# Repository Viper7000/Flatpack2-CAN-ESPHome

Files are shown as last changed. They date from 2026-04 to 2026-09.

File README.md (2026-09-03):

# Flatpack2-CAN-ESPHome
Controller board for monitor and configure Eltek Flatpak2 HE PSU by CANBUS protocol using ESPhome.
Config for ESP32-Nodemcu-32 and ESP32-S3-Zero.
Included fonts and images for ESPHome.

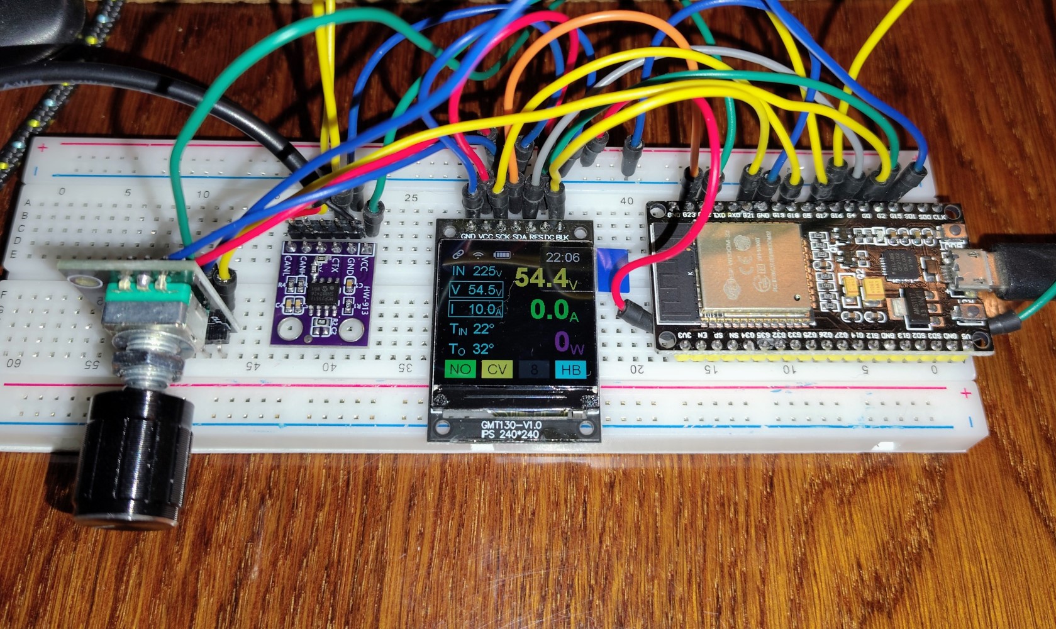
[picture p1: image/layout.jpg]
layout


## Schematics

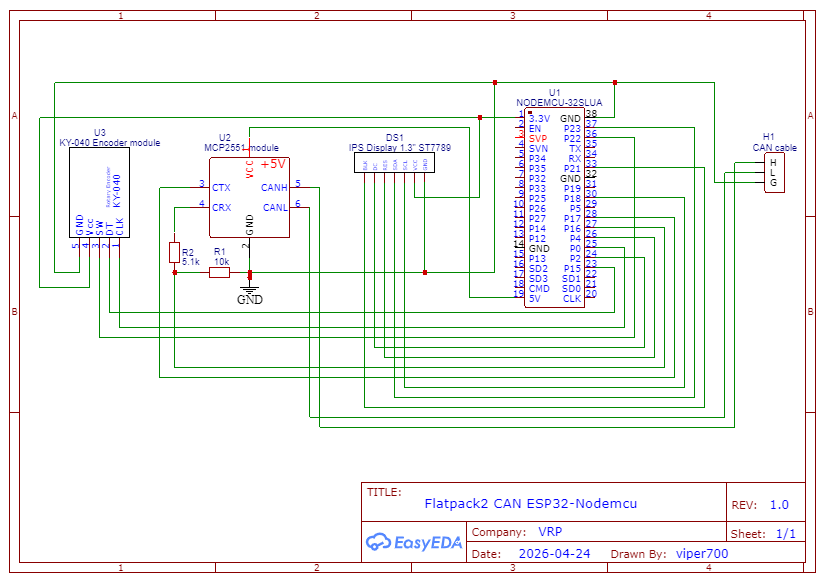
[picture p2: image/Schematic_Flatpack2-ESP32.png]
layout ESP32


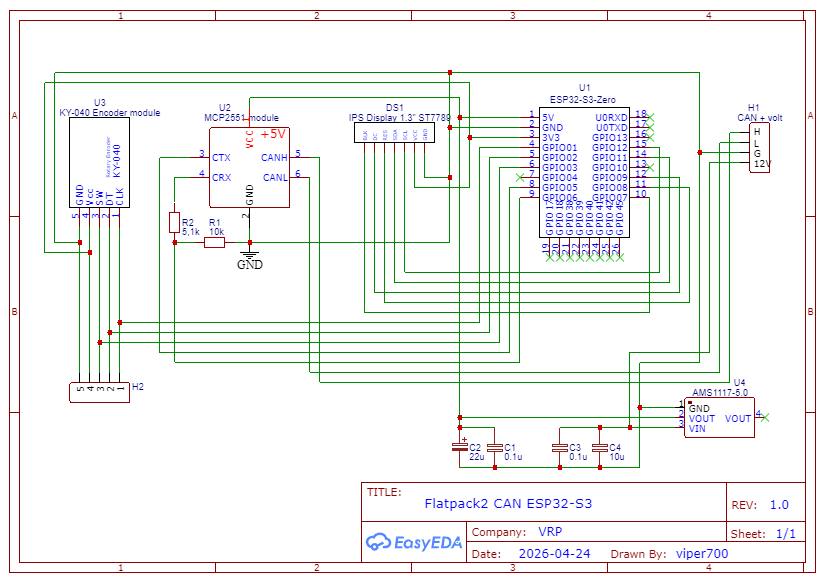
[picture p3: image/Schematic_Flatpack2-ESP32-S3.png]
layout ESP32-S3


I decided to assemble it on the ESP32-S3. I designed the board and sent the order to JLCPCB.  
Here is the [Gerber](files/Gerber_Flatpack2-ESP32-S3_PCB.zip) for ordering the PCB and the [BOM](files/BOM_Flatpack2-ESP32-S3.csv) file of components.  
I received the boards from JLCPCB for this power supply.  

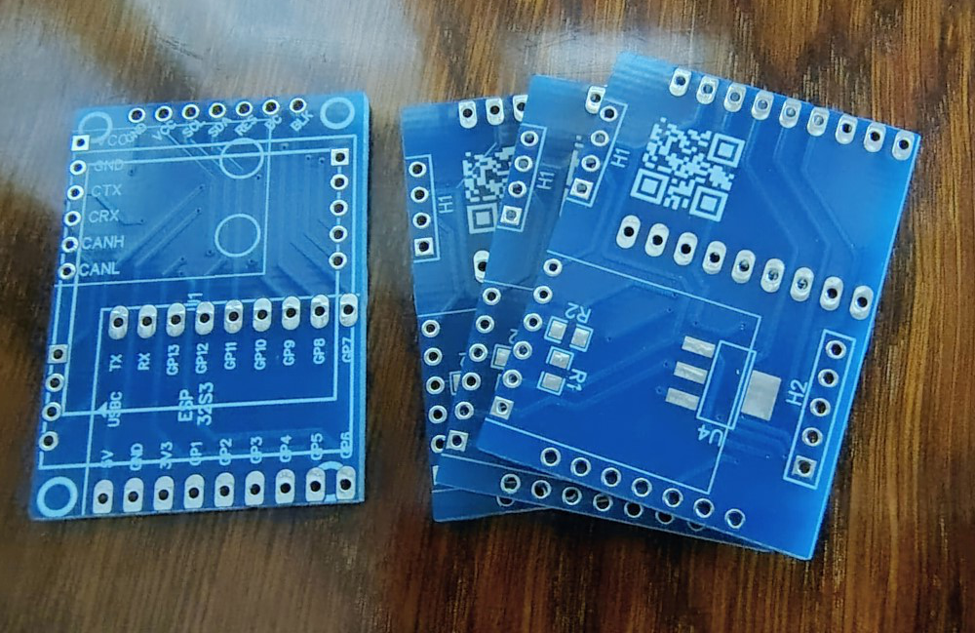
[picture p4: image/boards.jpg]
layout Boards


> :warning: This board has an error: the ASM1117-5.0 is missing a capacitor harness. This error has been fixed in the BOM and Gerber. I didn't print a new board and fixed it by surface-mounting the capacitors. The lack of capacitors resulted in interference, and sometimes the display would freeze or disappear.

## Test printing of enclosure on a 3D printer

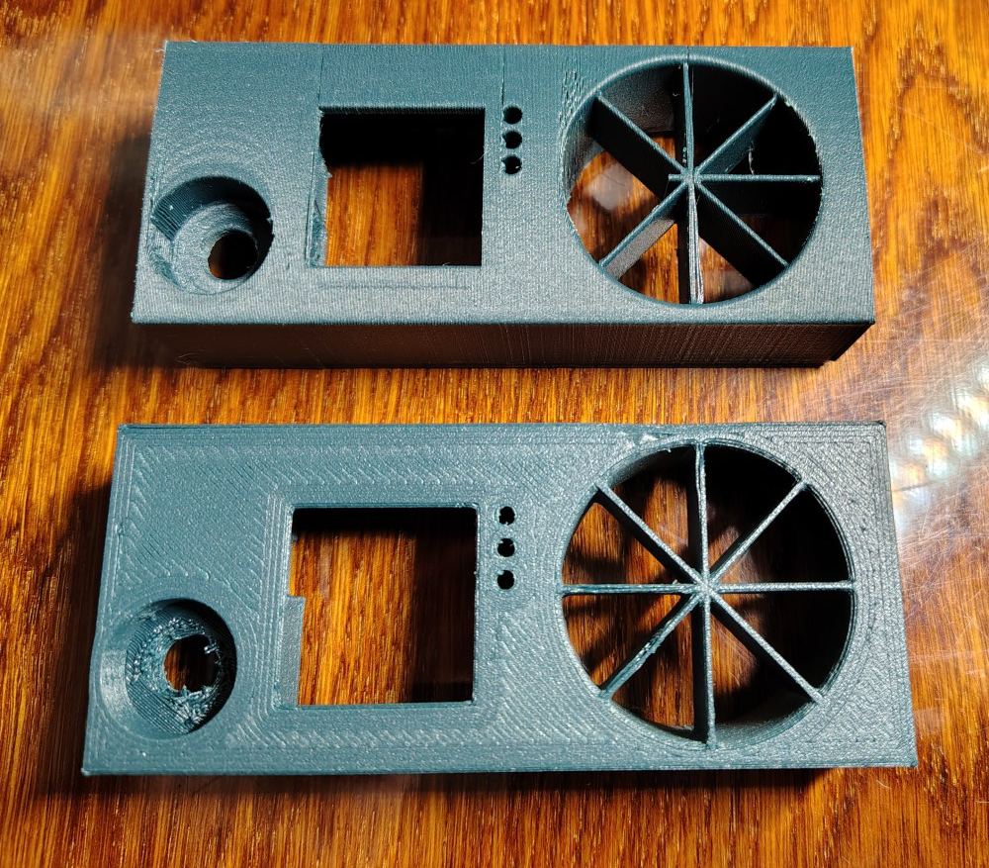
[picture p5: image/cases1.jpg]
layout Cases


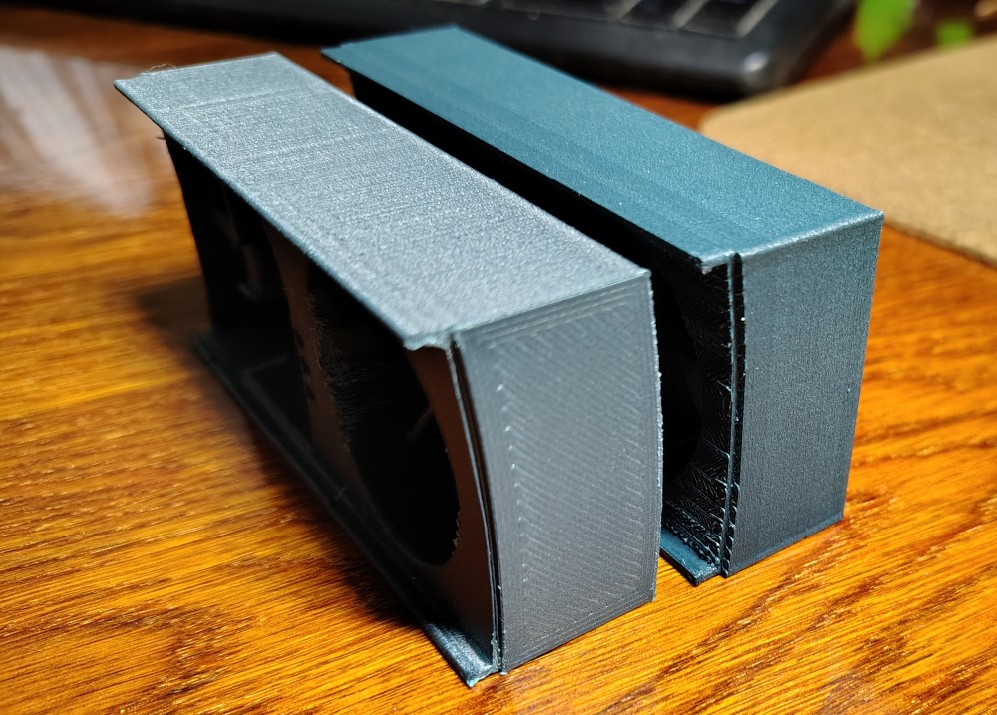
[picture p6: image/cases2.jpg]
layout Cases


The [first enclosure](files/Flatpack2_cover_final.stl) is for vertical printing on its side. It has a rounded face.  
The [second enclosure](files/Flatpack2_cover_final_flat.stl) is for horizontal printing. Printing is much easier! Flat front side with first layer pattern.  
The [third enclosure](files/Flatpack2_cover_final_support.stl) hasn't been printed yet. It's printed at 45 degrees and has a rounded face. This should make printing easier and improve quality. Additional support is required!  

### I assembled the board and installed it in the case.

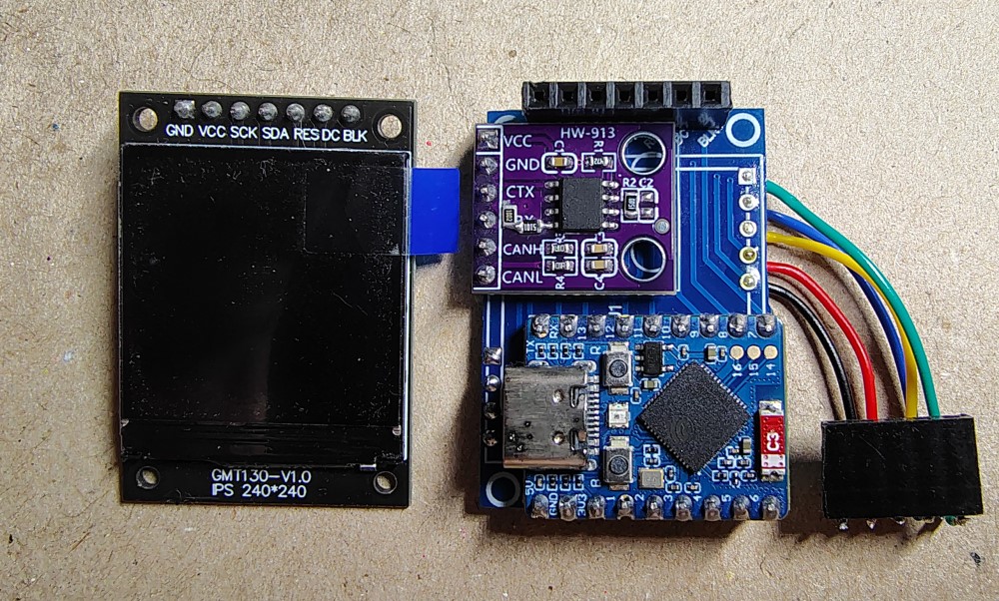
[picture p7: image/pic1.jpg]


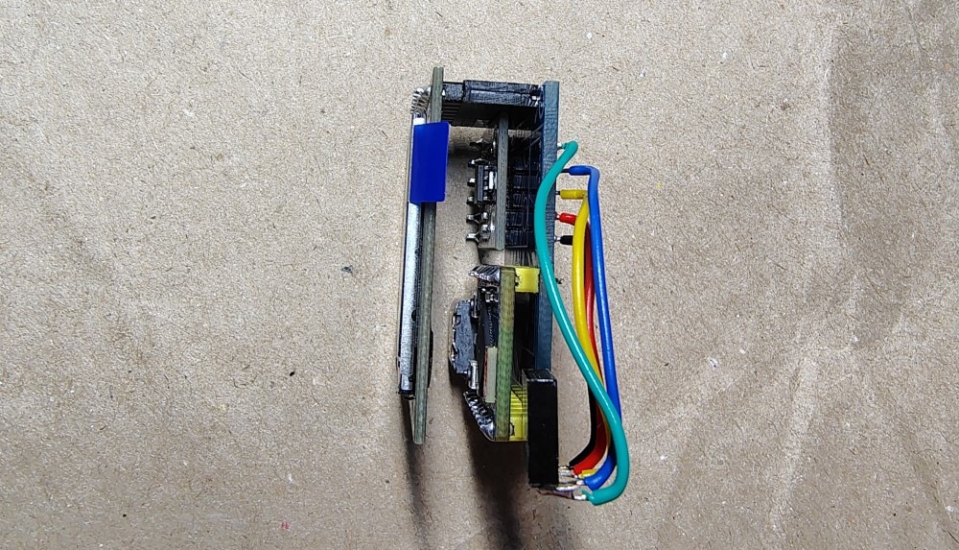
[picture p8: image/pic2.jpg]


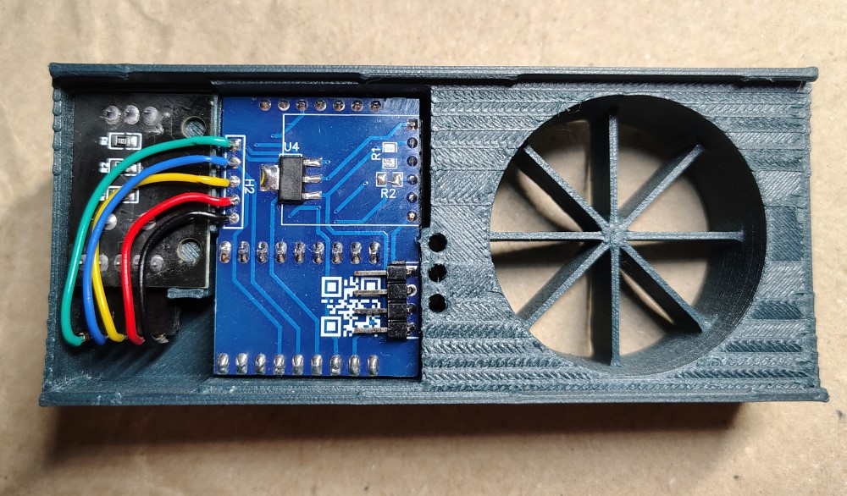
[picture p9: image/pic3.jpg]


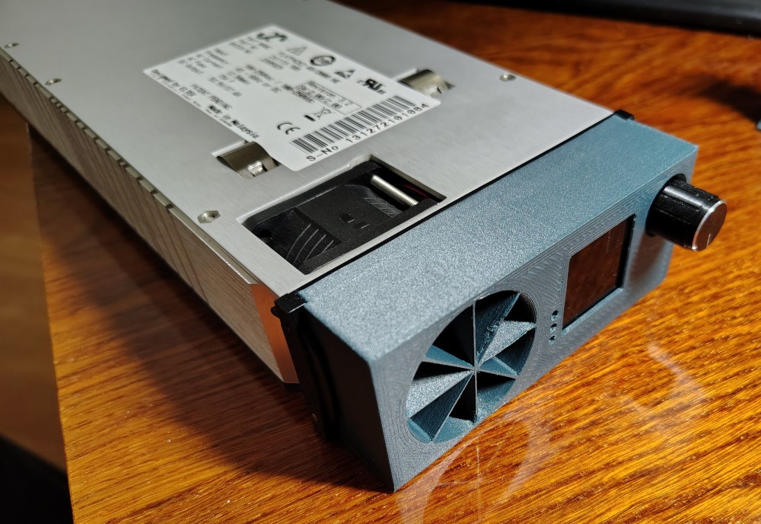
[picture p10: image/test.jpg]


## Connecting to the PSU. 
I get 12V from the fan's power supply. There's always power there! 

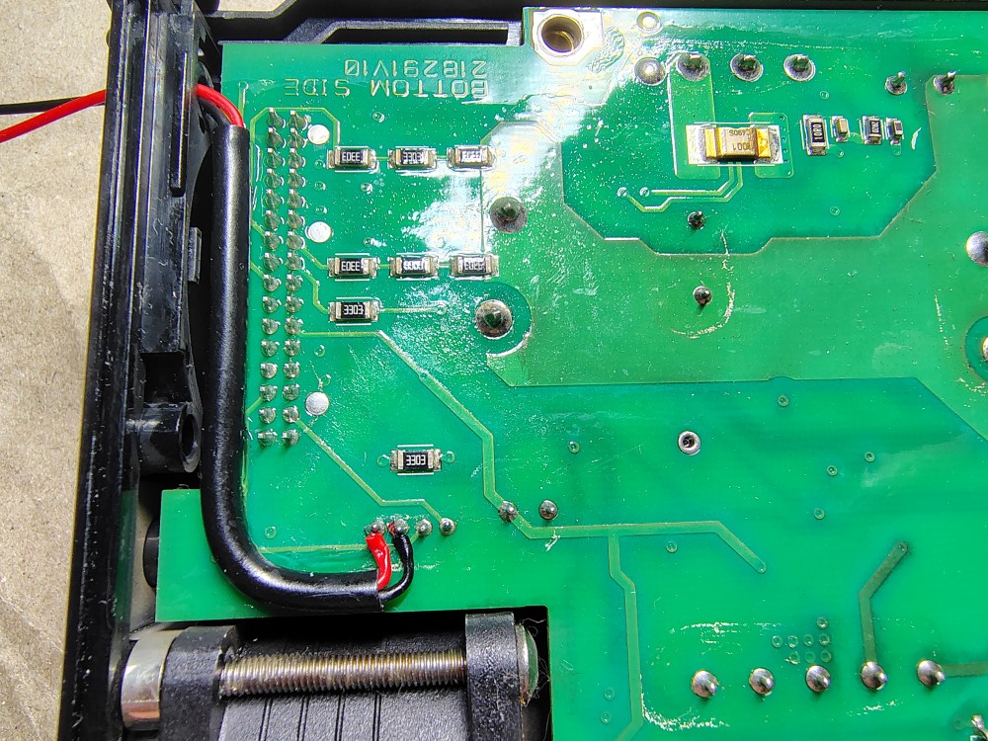
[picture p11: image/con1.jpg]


I laid the wires from the CAN and fixed them so they wouldn't dangle.
I routed all the wires to the front panel.

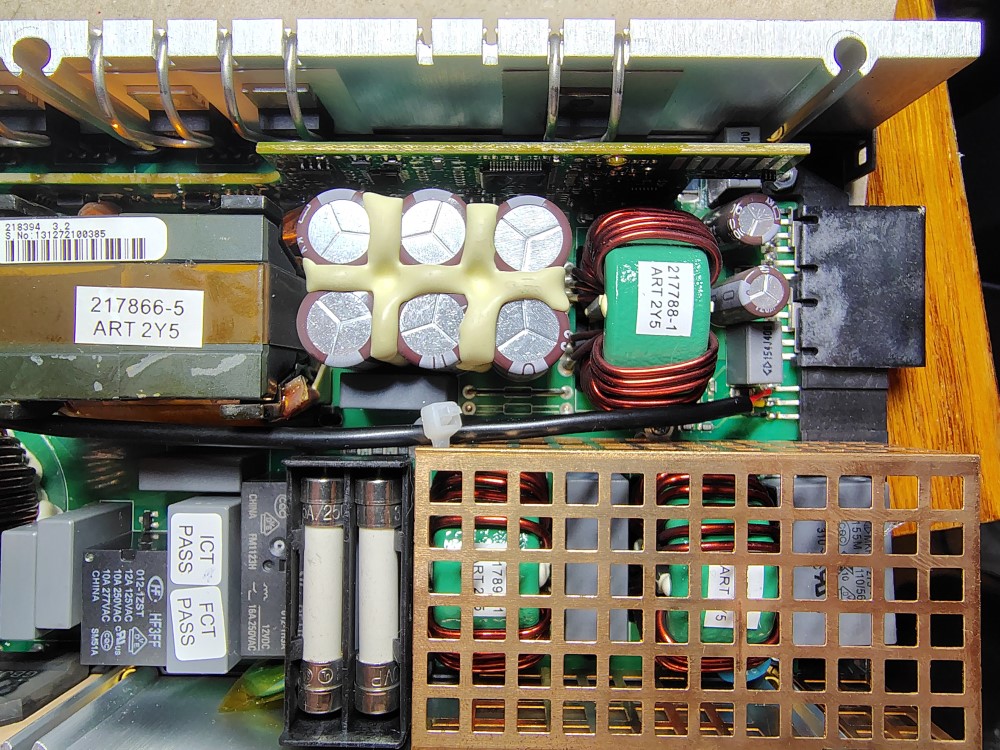
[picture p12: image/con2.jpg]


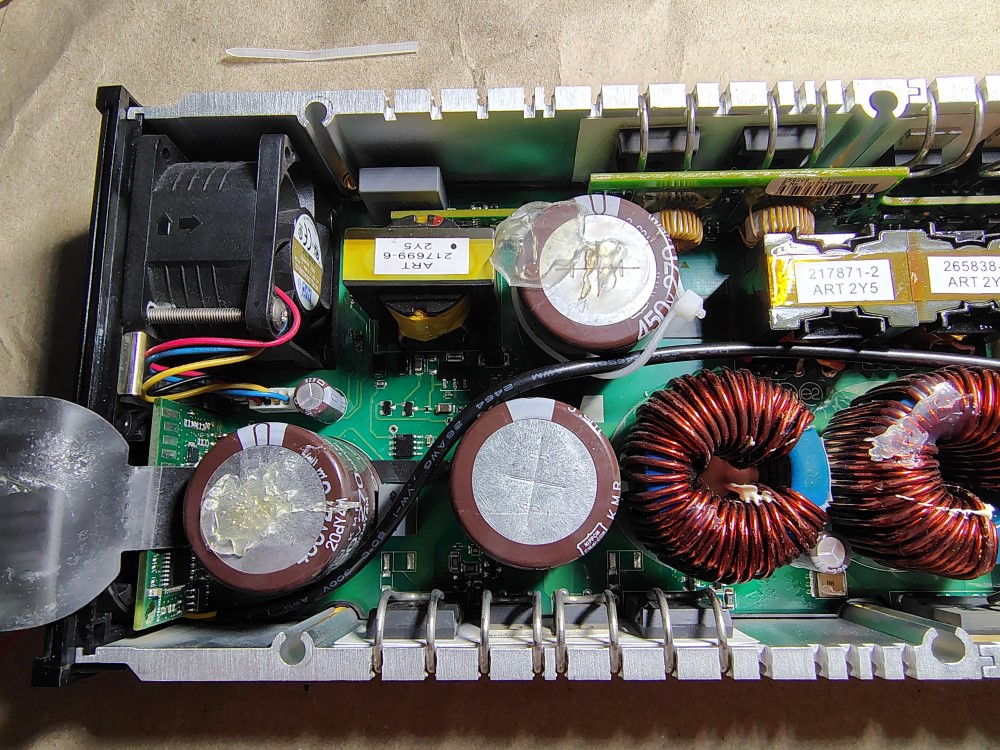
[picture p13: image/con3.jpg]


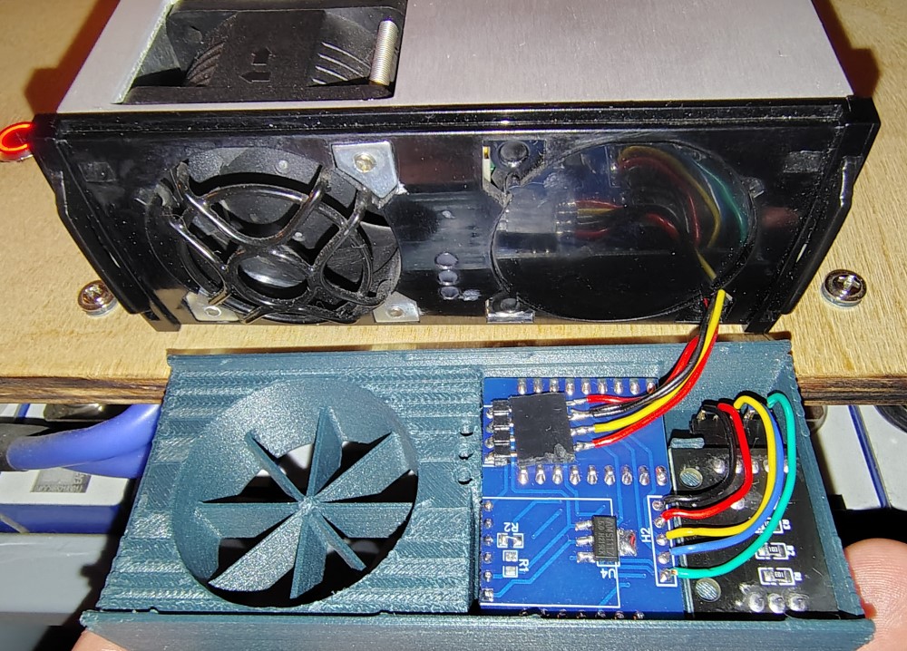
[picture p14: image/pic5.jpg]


> :warning: The CAN ground and the power ground must be connected together.

## The final appearance of the device

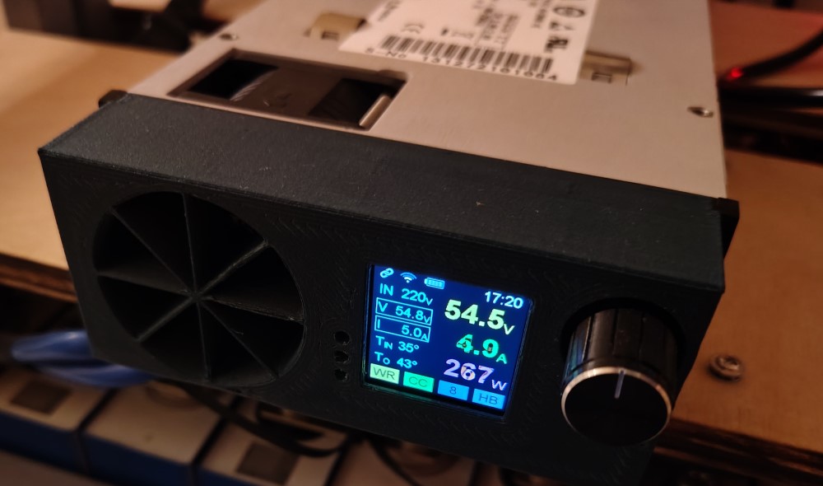
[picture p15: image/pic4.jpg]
final wires


Top line: CAN connected, WiFi signal, Battery (from HA), Time (from HA)  
Bottom line: Status (Normal, Warning, Alarm), Mode (CV, CC), Brightness (1-10), Heartbeats (Every packet from CAN)  

On the left in the frame are the set values of current and voltage, on the right are the actual values  

## Controls
Single press - set current. Turn the encoder. Single press - save.  
Double press - set voltage. Turn the encoder. Single press - save.  
Hold the button for 2 seconds - adjust brightness. Turn the encoder. Single press - save.

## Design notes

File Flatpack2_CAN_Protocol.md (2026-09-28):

# Flatpack2 CAN Protocol

## Conventions in This Document
__MSG__ is a message from the power supply to the controller.  
__CMD__ is a message from the transceiver to the power supply.  
__XX__ is ID of PSU (Set during login)

##  Hardware
The Flatpack2's CAN bus runs at 125kbit/s, using an extended ID field, referenced to the PSU's negative rail.  
It is necessary to connect the GND contact of your CAN bus to the CAN bus GND contact of your power supply.  

## Notes
Everything written in this document was tested exclusively on the Flatpack2 HE 48V/2000W. I use the MSP2551 transceiver.

## Operating Principle
When turned on, the PSU sends a Hello packet approximately every 2 seconds (containing the power supply serial number).
After you sending the Login command, the PSU sends a Status packet approximately every 0.2 seconds (containing the current voltages and temperatures).
After 64 Status packets, a logout occurs. After that, a Login request packet arrives approximately every 10 seconds. After sending the Login command, you will receive the Status packet again.
Without the Login command, the PSU sets the default voltage and has no current limit. After the Login command, you set the voltage and current limit. After the Logout, it reverts to the default voltage and no current limit. To ensure your parameters remain consistent, send the Login command before receiving the 64 Packet Status.
In Login mode, the PSU responds to your requests; in Logout mode, the PSU ignores everything except Login.

## MSG Hello packet, 0x0500XXXX (0x1b, serial[1-6], 0x00)
PSU sends a Hello packet approximately every 2 seconds (containing the power supply serial number) if not logged in; XXXX = last digits of the serial number

> :memo: **Example:**
> ```
> MSG 05005566, 1b 11 22 33 44 55 66 00 - Serial is 112233445566
> ```

## CMD Log in command, 0x050048XX (serial[1-6], 0x00, 0x00)	
Log in to a power supply and assign it a CAN ID. Serial number payload chooses which supply to target.
PSU ID is assigned by setting XX to (ID * 4), e.g. sending message ID 0x05004804 assigns PSU ID of 0x01 for future commands.
Allowable ID range is 0x01 to 0x3F , or an XX of 0x04 through 0xFC , and the power supply will log out if no login packet is received for (64 * 0.2) seconds.

> :memo: **Example:** Login, serial is 112233445566, ID is 01
> ```
> CMD 05004804, 11 22 33 44 55 66 00 00
> ```

## MSG Status packet, 0x05XX40YY (intemp, Iout[2], Vout[2], Vin[2], outtemp)
After you sending the Login command, the PSU sends a Status packet approximately every 0.2 seconds (containing the current voltages and temperatures). After 64 Status packets, a logout occurs. XX is PSU ID. 
Current, output voltage and input voltage are stored in little endian (LSB first). All temperatures are in degrees Celsius. Current is in deciamps (i.e. 21.2A is 212). Output voltage is in centivolts (i.e. 48.52V is 4852). Input voltage is in volts.

#### YY is Status flags:
YY | State
:------:|:--------------------------
0x04 | normal (constant voltage)
0x08 | warning (constant current)
0x0c | alarm
0x10 | walk in

> :memo: **Example:** intemp 35(0x23) °C, Iout - 10A(100=0x64), Vout - 54.8V(5480=0x1568), Vin - 230V(0xe6), outtemp - 55(0x37) °C
> ```
> MSG 05014004, 23 64 00 68 15 e6 00 37
> ```

## MSG Log in request packet, 0x05XX4400 (serial[1-6], 0x00, 0x00) xx=ID каждые 10 сек
After 64 Status packets, a logout occurs. After that, a Login request packet arrives approximately every 10 seconds. Similar to the CAN hello packet, but uses supply's pre-set ID. After sending the Login command, you will receive the Status packet again.
XX is PSU ID.

> :memo: **Example:** serial is 112233445566, ID is 01
> ```
> MSG 05014400, 11 22 33 44 55 66 00 00
> ```

## CMD Alert request command, 0x05XXbffc (0x08, 0x04 warn/0x08 alarm, 0x00)
This is sent to the PSU to request information about current warnings and alarms. The command should be sent after receiving message 0x05XX40YY, where YY = 08 or YY = 0C (i.e., when a warning or alarm is present). The second byte determines which information is returned: warning or alarm data.

> :memo: **Example:** 0x04 - warnings request
> ```
> CMD 0501bffc, 08 04 00
> ```

## MSG Alert information packet, 0x05XXbffc (0x0e, 0x04/0x08, 0x00, Alert flag1, Alert flag2, 0x00, 0x00)
Sent by the PSU in response to receiving message 0x05XXBFFC. It contains information about any active alarms or warnings, depending on the content of the request message. 2nd byte indicates whether flag bits are warning or critical, and is equal to 2nd byte of CMD packet.
XX is PSU ID. Bit 0 is the LSB.

#### Warnings/Alarms
Bit | Warning/alarm flag1 | Warning/alarm flag2
:---:|:--------------------|:--------------------
0 | OVS Lock Out | Internal Voltage
1 | Mod Fail Primary | Module Fail
2 | Mod Fail Secondary | Mod Fail Secondary
3 | High Mains | Fan 1 Speed Low
4 | Low Mains | Fan 2 Speed Low
5 | High Temp | Sub Mod1 Fail
6 | Low Temp | Fan 3 Speed Low
7 | Current Limit | Inner Volt

> :memo: **Example:** Warning, Current Limit
> ```
> MSG 0501bffc, 0e 04 00 80 00 00 00
> ```

## CMD Set voltage and current limits command, 0x05XX4004 (max_cur[2], meas_vol[2], des_vol[2], OVP_vol[2])
Sent to the PSU to immediately set output voltage and current limits.
If the supply logs out, these settings will be lost - default voltage will apply, and current limit will be set to factory maximum. Max current (max_cur[2]) is the point at which the supply will switch from CV to CC modes. 
Desired voltage is the output voltage setpoint.
Measured voltage is for calibration/feedback; if you do not have a feedback voltage source, it should be equal to desired voltage.
OVP voltage is the voltage at which over-voltage protection will enable & cause the supply to shut down. Set this to your supply's maximum rated output voltage.
XX is PSU ID. Set XX to ff to send all PSU

> :memo: **Example:** Max 10A(100=0x64), meas_vol[2]=des_vol[2], MaxV - 54.8V(5480=0x1568), OVP - 56V(5600=0x15e0)
> ```
> CMD 05ff4004, 64 00 68 15 68 15 e0 15
> ```

## CMD Set default voltage command, 0x05XX9c00 (0x29, 0x15, 0x00, new_volt[2])
Sent to the power supply to set its default voltage. Does not take effect until the supply is logged out. If the supply is logged in when the command is sent, the voltage is set when the log in times out. If it is not logged in, the voltage will be set when the supply logs in then times out. The voltage is stored in little-endian and is in centivolts (i.e. 48.52V is 4852).
XX is PSU ID.

> :memo: **Example:** DefV - 54.8V(5480=0x1568)
> ```
> CMD 05019c00, 29 15 00 68 15
> ```

## CMD Information request command, 05XXbc00 (0x50, ZZ, 0x00)
Sent to the PSU information request. 
ZZ is 0x00 - Model, 0x04 - Part No, 0x08 - Serial No, 0x0c - Revision
XX is PSU ID. 

> :memo: **Example:**
> ```
> CMD 0501bc00, 50 00 00 - Model request command
> CMD 0501bc00, 50 04 00 - Part No request command
> CMD 0501bc00, 50 08 00 - Serial No request command
> CMD 0501bc00, 50 0c 00 - Revision request command
> ```

## MSG Information response packet, 05XXbc00
The response arrives in several packets. Below are examples of responses. XX is PSU ID. 

> :memo: **Example:** Model response - FLATPACK2 48/2000 HE
> ```
> MSG 0501bc00, 53 00 86 46 4C 41 54 50 - FLATP
> MSG 0501bc00, 53 00 05 41 43 4B 32 20 - ACK2
> MSG 0501bc00, 53 00 04 34 38 2F 32 30 - 48/20
> MSG 0501bc00, 53 00 03 30 30 20 48 45 - 00 HE
> MSG 0501bc00, 53 00 02 00 00 00 00 00 -
> MSG 0501bc00, 53 00 01 00 00 90 FB 3F - \x90\xfb?
> ```

> :memo: **Example:** Part No response - 241115.105
> ```
> MSG 0501bc00, 53 04 83 32 34 31 31 31 - 24111
> MSG 0501bc00, 53 04 02 35 2E 31 30 35 - 5.105
> MSG 0501bc00, 53 04 01 00 00 90 FB 3F - \x90\xfb?
> ```

> :memo: **Example:** Serial No response - 112233445566
> ```
> MSG 0501bc00, 53 08 82 11 22 33 44 55 - 
> MSG 0501bc00, 53 08 01 66 C4 90 FB 3F - \x84Đ\xfb?
> ```

> :memo: **Example:** Revision response - 3.2
> ```
> MSG 0501bc00, 53 0C 82 33 2E 32 00 00 - 3.2
> MSG 0501bc00, 53 0C 01 00 C4 90 FB 3F - Đ\xfb?
> ```

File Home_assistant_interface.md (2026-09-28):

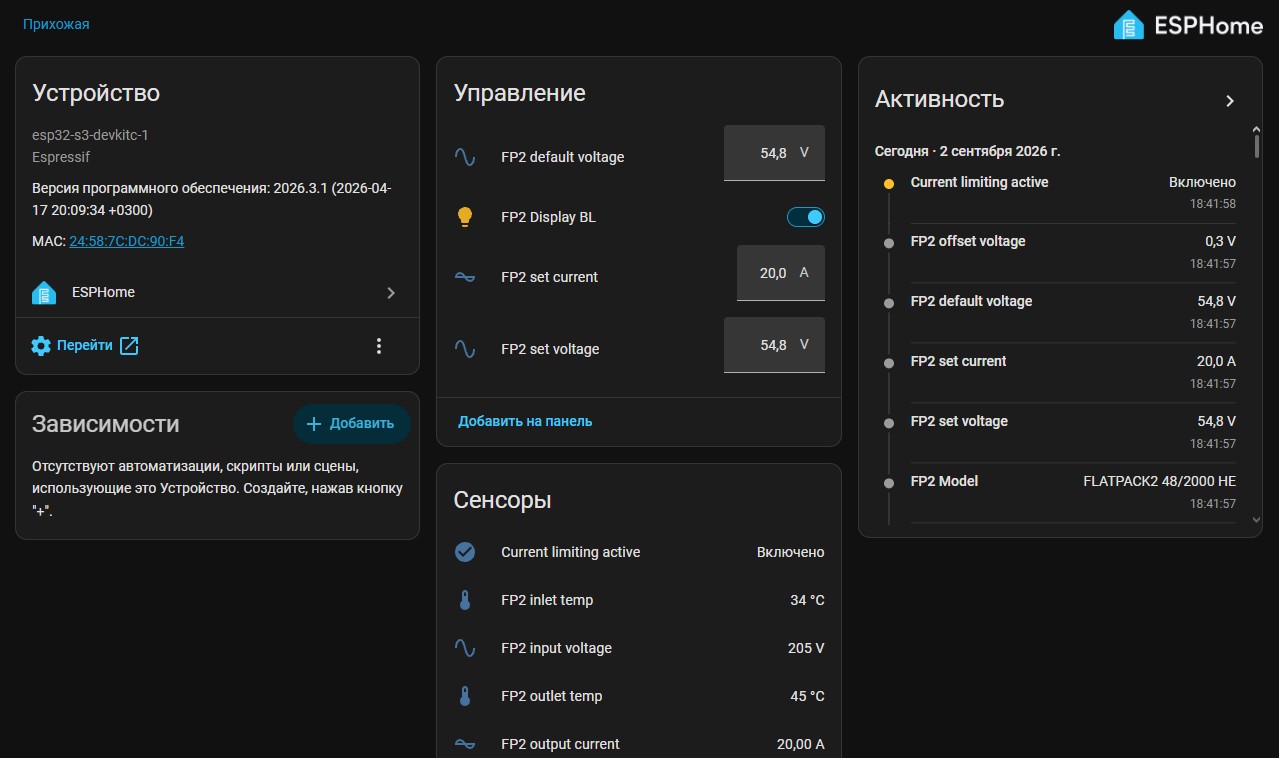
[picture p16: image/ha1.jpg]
HA 1
  

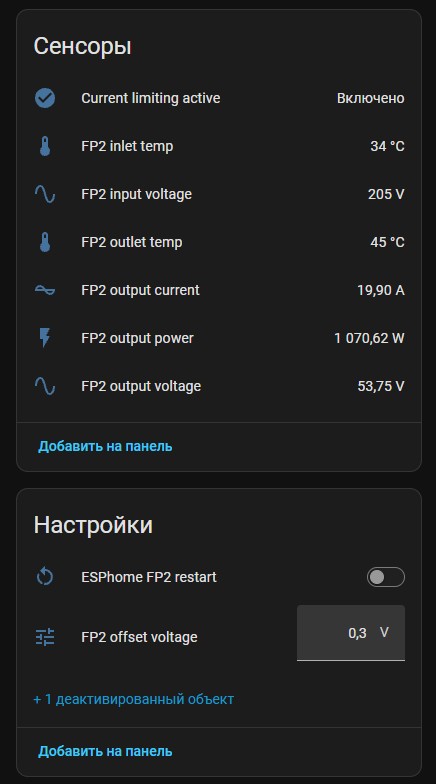
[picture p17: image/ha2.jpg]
HA 2
  

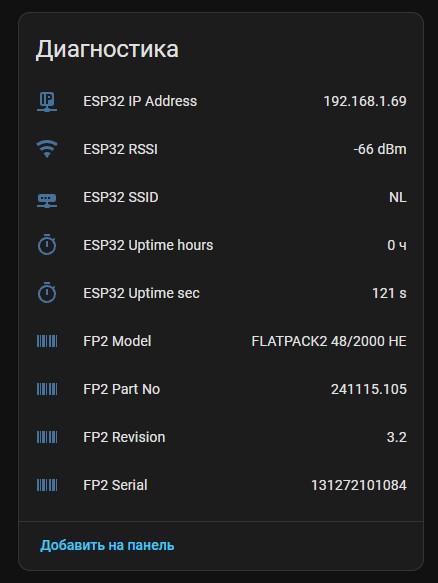
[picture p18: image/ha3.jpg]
HA 3


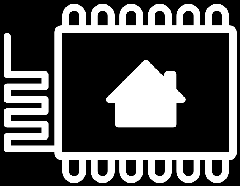
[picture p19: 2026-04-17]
yaml/esphome/images/esphome.png

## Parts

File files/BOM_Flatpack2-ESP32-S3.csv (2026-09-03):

ID | Name | Designator | Footprint | Quantity | Manufacturer Part | Manufacturer | Supplier | Supplier Part | Price
1 | 0.1u | C1,C3 | C0805 | 2
2 | 10u | C4 | C0805 | 1
3 | 22u | C2 | CASE-B_3528 | 1
4 | 10k | R1 | R0805 | 1
5 | 5,1k | R2 | R0805 | 1
6 | AMS1117-5.0 | U4 | SOT-223-3_L6.5-W3.4-P2.30-LS7.0-BR | 1 | AMS1117-3.3 | AMS | LCSC | C6186 | 0.219
7 | HDR-F-2.54_1x5 | H2 | HDR-F-2.54_1X5 | 1 |  |  | LCSC | C50950 | 0.088
8 | CAN + volt | H1 | HDR-F-2.54_1X4 | 1 |  |  | LCSC | C225501 | 0.098
9 | IPS Display 1.3" ST7789 | DS1 | 1.3"_LCD_ST7789_7PIN | 1 | ST7789 | Chinese | Mouser
10 | ESP32-S3_SMD | U1 | ESP32-S3-ZERO | 1 | ESP32-S3 H4N2 | ESPRESSIF | ESPRESSIF
11 | MCP2551 module | U2 | MCP2551 | 1

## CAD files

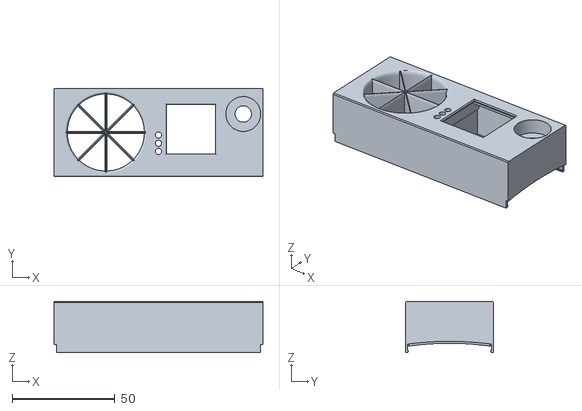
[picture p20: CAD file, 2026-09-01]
files/Flatpack2_cover_final_flat.stl
101.8 x 43.0 x 25.0

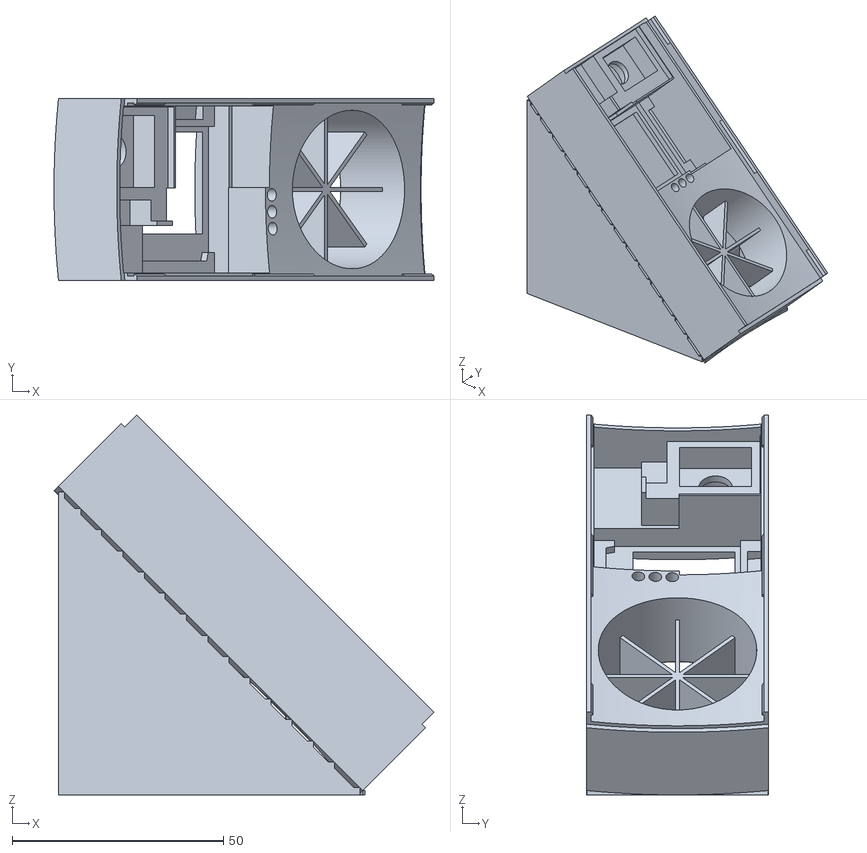
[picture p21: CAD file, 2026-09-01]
files/Flatpack2_cover_final_support.stl
89.9 x 43.0 x 89.9

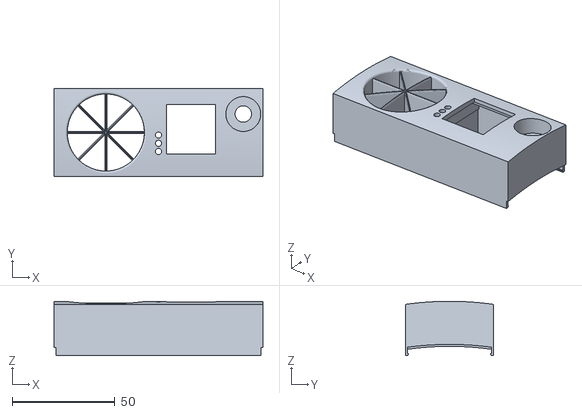
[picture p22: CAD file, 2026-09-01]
files/Flatpack2_cover_final.stl
101.8 x 43.0 x 26.5

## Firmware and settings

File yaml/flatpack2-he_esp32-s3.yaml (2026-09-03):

esphome:
  name: flatpack2-he
  friendly_name: Flatpack2 HE 48/2000
  platformio_options:
    board_build.flash_mode: dio # If you don't specify this using esp-idf framework, the device will boot-loop.
  on_boot:
    then:
      - display.page.show: page1
      - light.turn_on: 
          id: back_light
          brightness: 80%

esp32:
  board: esp32-s3-devkitc-1
  variant: esp32s3
  flash_size: 4MB
  framework:
    type: esp-idf

psram:
  mode: quad
  speed: 80MHz 

#debug:
#  update_interval: 5s

# Enable logging
logger:
  level: INFO #DEBUG

# Enable Home Assistant API
api:
  encryption:
    key: "zsjqfraKRnbSZ9K8Kpoov5XBcwz/OstygTuYcvSvNeU="

ota:
  - platform: esphome
    password: wifi_password

wifi:
  networks:
  - ssid: !secret wifi_ssid
    password: !secret wifi_password
  - ssid: !secret wifi_ssid2
    password: !secret wifi_password2
  - ssid: !secret wifi_ssid3
    password: !secret wifi_password3

  # Optional manual IP
  manual_ip:
    static_ip: 192.168.1.69
    gateway: 192.168.1.1
    subnet: 255.255.255.0
    dns1: 192.168.1.50
    dns2: 192.168.1.1

  # Enable fallback hotspot (captive portal) in case wifi connection fails
  ap:
    ssid: "Flatpack2-He Fallback Hotspot"
    password: wifi_password

captive_portal:

web_server:
  port: 80

globals:
  - id: temp_inlet
    type: int
    restore_value: no
    initial_value: '0'
  - id: temp_outlet
    type: int
    restore_value: no
    initial_value: '0'
  - id: voltage_input
    type: int
    restore_value: no
    initial_value: '0'
  - id: voltage_set
    type: float
    restore_value: no
    initial_value: '54.5'
  - id: voltage_output
    type: float
    restore_value: no
    initial_value: '0'
  - id: current_set
    type: float
    restore_value: no
    initial_value: '20.0'
  - id: current_output
    type: float
    restore_value: no
    initial_value: '0'
  - id: serial_number
    type: uint8_t[6]
  - id: rev_str
    type: char[7]
  - id: part_str
    type: char[13]
  - id: model_str
    type: char[28]
  - id: current_limiting
    type: bool
    initial_value: 'false'
  - id: canl
    type: int
    restore_value: no
    initial_value: '0'
  - id: mode
    type: int
    restore_value: no
    initial_value: '0'
  - id: brightness
    type: int
    restore_value: no
    initial_value: '80'
  - id: count
    type: int
    restore_value: no
    initial_value: '61'
  - id: flag
    type: int
    restore_value: no
    initial_value: '0'
  - id: HB
    type: int
    restore_value: no
    initial_value: '0'

font:
  - file: "fonts/arial.ttf"
    id: font1
    size: 16
    glyphs: |-
      VAINO
  - file: "fonts/arial.ttf"
    id: font2
    size: 24
    glyphs: |-
      HBVAWINTCRLO1234567890. °-:
  - file: "fonts/arialbd.ttf"
    id: font3
    size: 48
    glyphs: |-
      1234567890 .


color:
  - id: blue
    hex: 62e6e8
  - id: red
    hex: FF0000
  - id: green
    hex: 00FF00
  - id: yellow
    hex: FFFF00
  - id: white
    hex: FFFFFF
  - id: purple
    hex: A030B5
  - id: gray
    hex: "585858"
  - id: bkg
    hex: "000000"

#graph:

spi:
  clk_pin: 12
  mosi_pin: 11
  miso_pin: 13
  interface: spi2
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

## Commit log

2026-04-17 ESPHome ESP32 files
2026-04-17 Add ESP32-S3 config
2026-04-24 Schematic upload
2026-09-01 The SPI frequency has been reduced to 2 MHz
2026-09-01 Rename Flatpack2 cover_final.stl to Flatpack2_cover_final.stl
    [Flatpack2_cover_final.stl]
2026-09-01 Rename Flatpack2 cover_final_support.stl to Flatpack2_cover_final_support.stl
    [Flatpack2_cover_final_support.stl]
2026-09-01 Rename Flatpack2 cover_final_flat.stl to Flatpack2_cover_final_flat.stl
    [Flatpack2_cover_final_flat.stl]
2026-09-03 Updated BOM and Gerber
    [BOM_Flatpack2-ESP32-S3.csv]
